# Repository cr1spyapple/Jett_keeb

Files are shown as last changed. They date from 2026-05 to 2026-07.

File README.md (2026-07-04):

# JETT
<b> A wired 56 key split keyboard powered by RP2040 microcontrollers.
</b>

3D render:
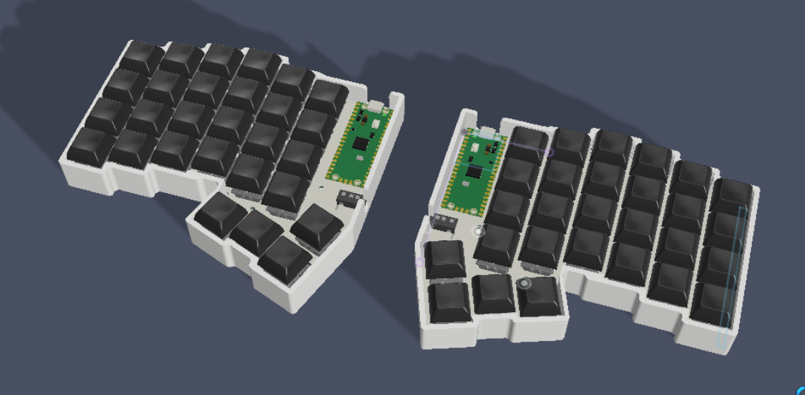
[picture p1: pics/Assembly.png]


Final build:
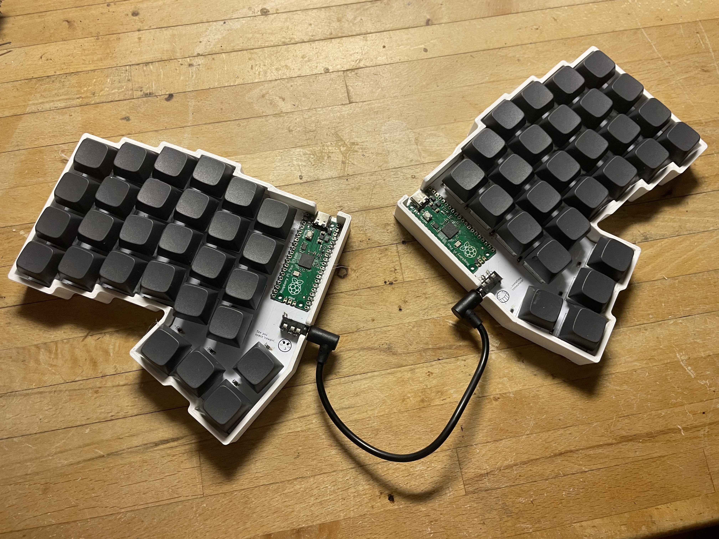
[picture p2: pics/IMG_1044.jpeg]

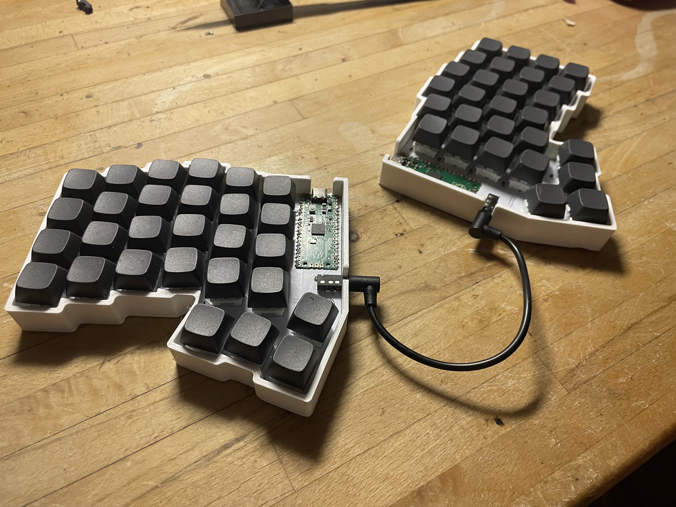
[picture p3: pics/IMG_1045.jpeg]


After creating the GOATPad i decided to take up a slightly more challenging twist to that project. This time a full split keyboard, which taught me how to panelize PCBs and make two MCU's communicate together.

  ### Specs
- Raspberry Pico microcontroller
- 56 keys
- MX Brown switches
- USB Type-C connectivity
- 3D Printed Case

## Schematic
### Left
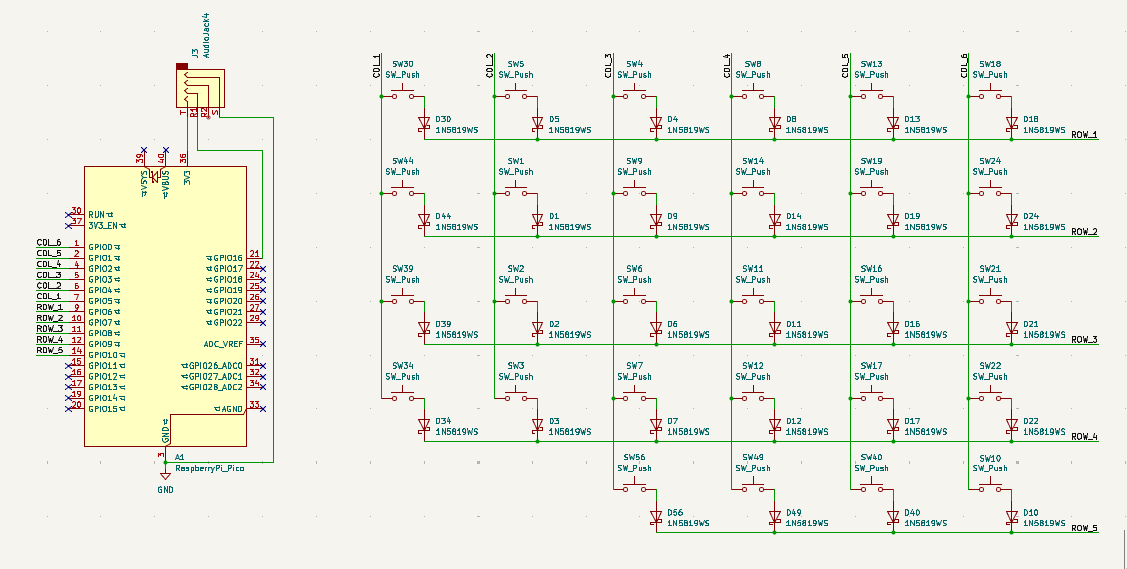
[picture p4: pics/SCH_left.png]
 

### Right
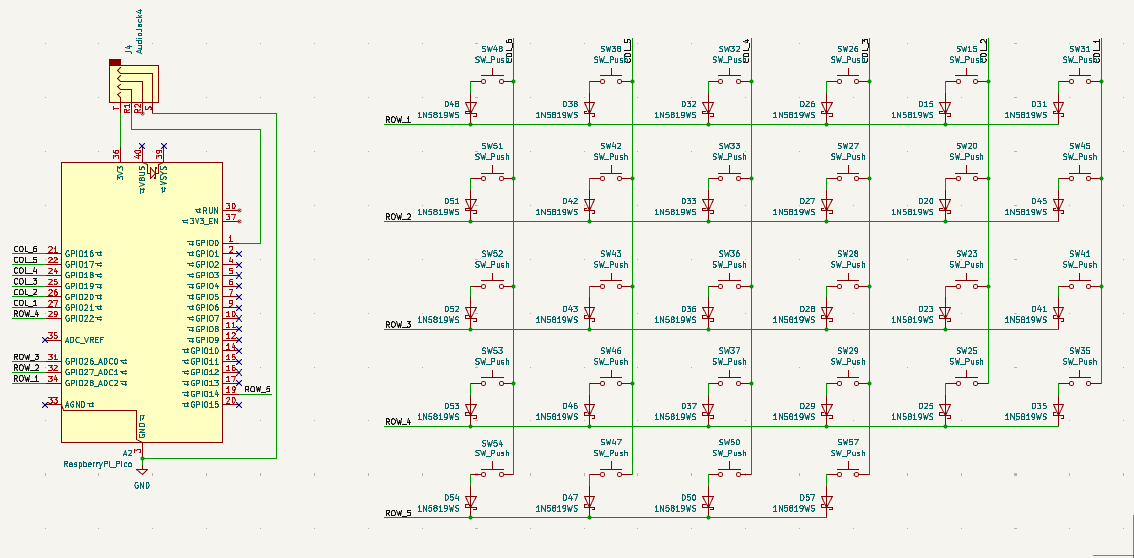
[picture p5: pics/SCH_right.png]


## PCB
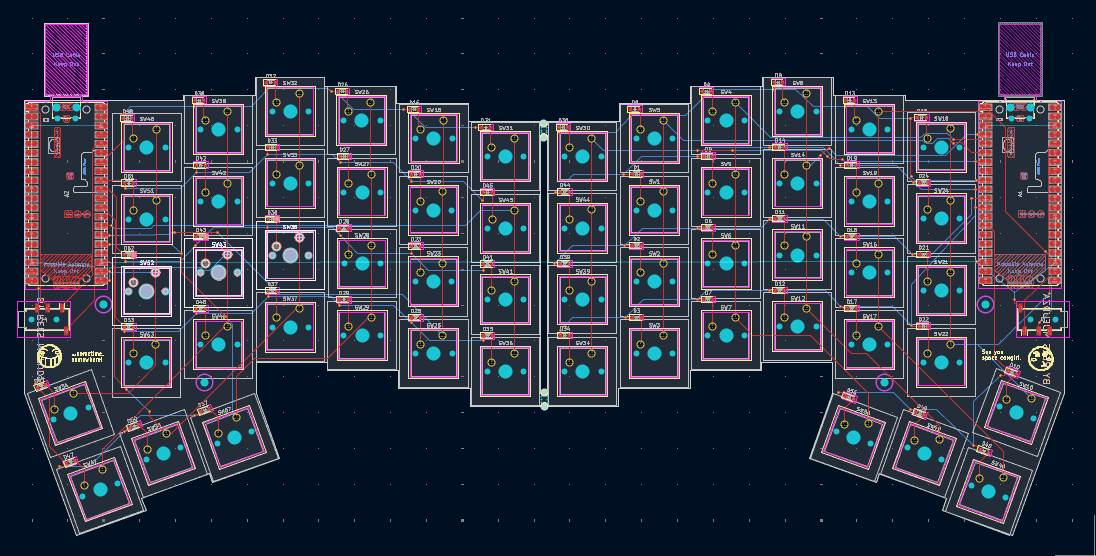
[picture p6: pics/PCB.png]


## Case
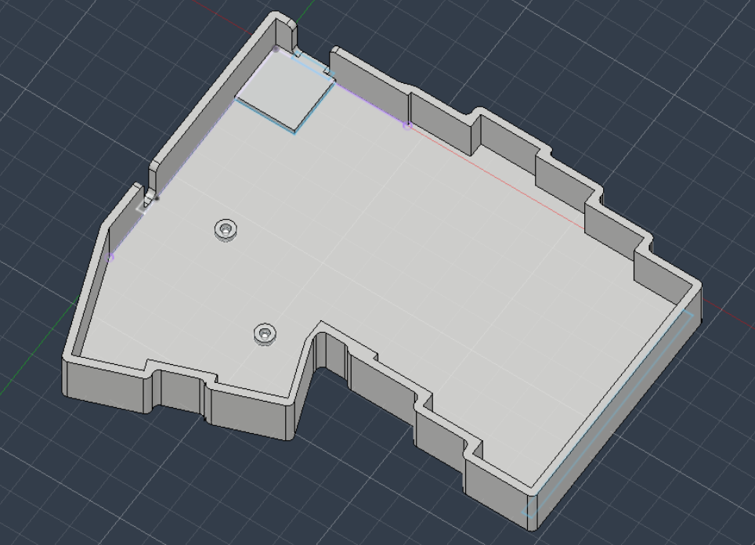
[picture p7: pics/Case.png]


## Bill of Materials

|Name |Purpose |Quantity|Total Cost (USD)|Link |Distributor|
|---|---|---|---|---|---|
|M2 Heat inserts |Screw holes in case |1 |1.95 |https://www.aliexpress.com/item/1005007640664497.html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|Aliexpress |
|M2 Screws |Mounting PCB to case |1 |1.35 |https://www.aliexpress.com/item/4000026780118.html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 |Aliexpress |
|3.5mm PJ-320D audio jack (10PCS) |Port for TRRS cable | |1.20 |https://www.aliexpress.com/item/4000661908135.html |Aliexpress |
|1N5819WS SOD-323 Diodes (100PCS) |Diodes for key matrix | |1.64 |https://www.aliexpress.com/item/1005006216984245.html |Aliexpress |
|Male-to-Male TRRS cable |For MCU's to share power and data|1 |2.50 |https://www.aliexpress.com/item/1005008288720867.html |Aliexpress |
|Black XDA Profile keycaps (64PCS)  |Key caps | |15.06 |https://www.aliexpress.com/item/1005011932744770.html?mp=1 |Aliexpress |
|MX style Brown key switches (80PCS)|Key switches | |6.91 |https://www.aliexpress.com/item/1005011838889689.html |Aliexpress |
|Raspberry Pico |Microcontroller |2 |4.55 |https://www.aliexpress.com/item/1005005617180169.html |Aliexpress |
|PCB |Keyboard PCB |5 |22.90 | |JLCPCB |
|  | TOTAL |  | 58.06 |  |  |

*Not including shipping and tax

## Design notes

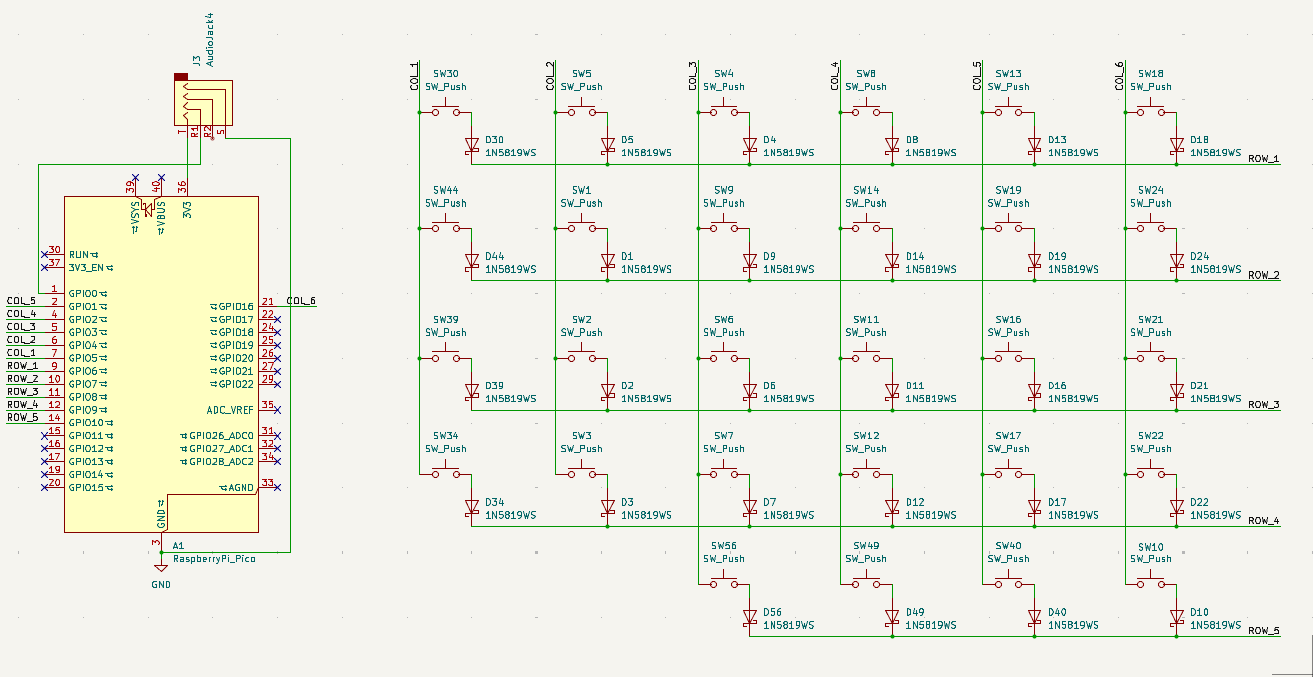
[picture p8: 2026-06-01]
pics/SCH_Left.png

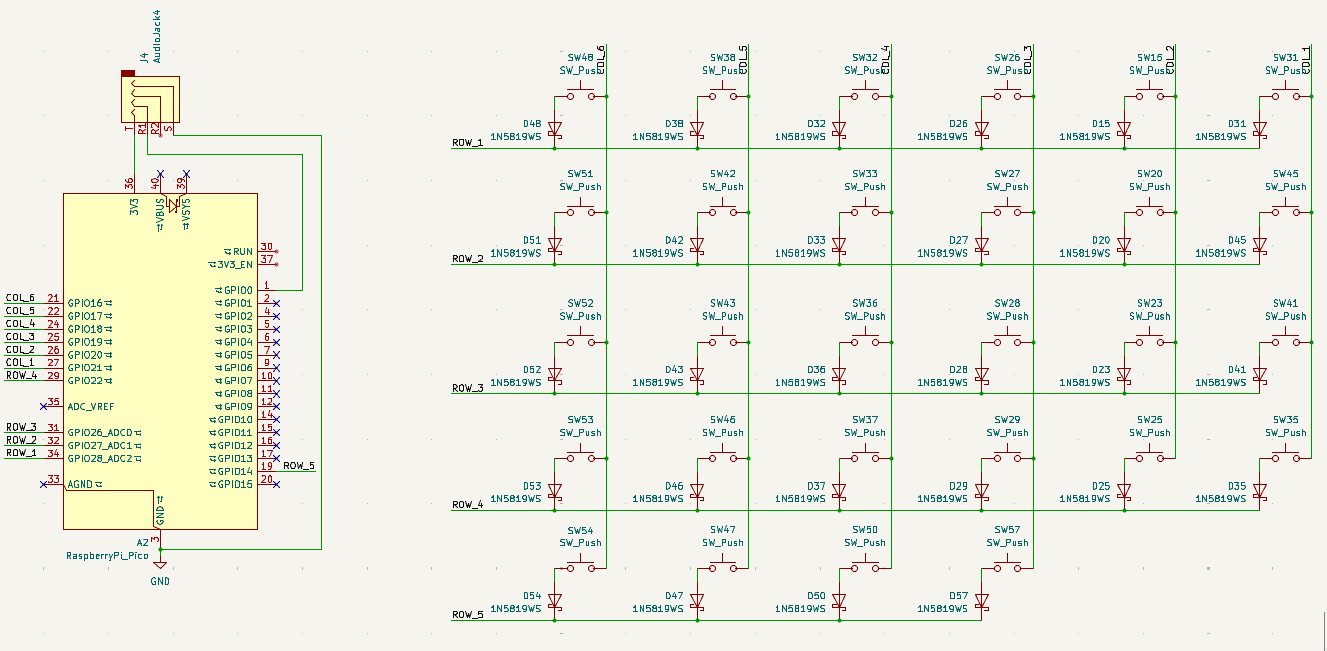
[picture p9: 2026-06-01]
pics/SCH_Right.png

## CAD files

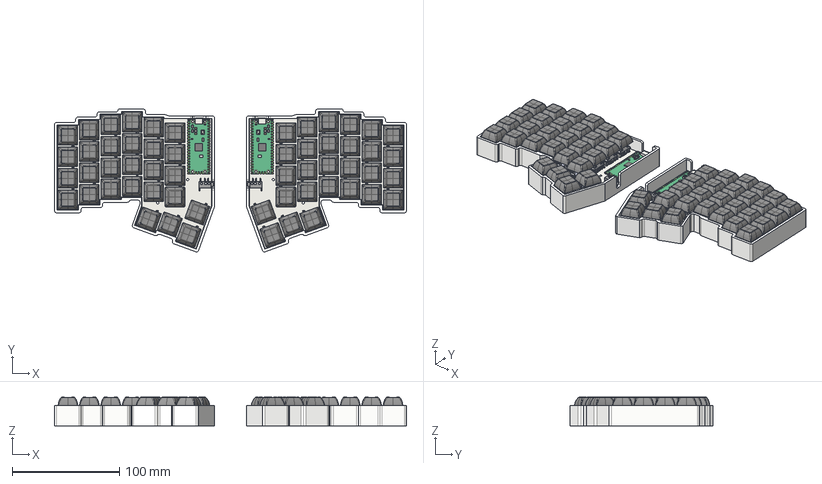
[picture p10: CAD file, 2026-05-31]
base (Assembly).step
328.7 x 133.4 x 26.7 mm
D_SOD-323 x 28
RaspberryPi_Pico_Module_KiCad
JETT_SPLIT_PCB
MX Öá °´¼ü¡ä_¨¹ ___¡§1 x 28
MX Öá ÖáÌå¨¢¨¬ _¡§¡é¡§__ x 28
MXÖá ÎÞÃ±LEDLEDLED x 28
MXÖá ÖáÌå µ×²¿ ¦Ì¡ Á2__Ä¬ÈÏ_¨¢2____¨¨_ x 28
Õë½Å___Ä¬ÈÏ__¨¨ _ x 28
Keycap_adjusted x 28
Composant1.step
audio_3.5mm_trrs.step
audio_3.5mm_trrs-0.step
audio_3.5mm_trrs-1.step
audio_3.5mm_trrs-2.step
audio_3.5mm_trrs-3.step
audio_3.5mm_trrs-4.step
audio_3.5mm_trrs-5.step
audio_3.5mm_trrs-6.step
audio_3.5mm_trrs-7.step
audio_3.5mm_trrs-8.step
audio_3.5mm_trrs-9.step
audio_3.5mm_trrs-10.step
audio_3.5mm_trrs-11.step
audio_3.5mm_trrs-12.step
audio_3.5mm_trrs-13.step

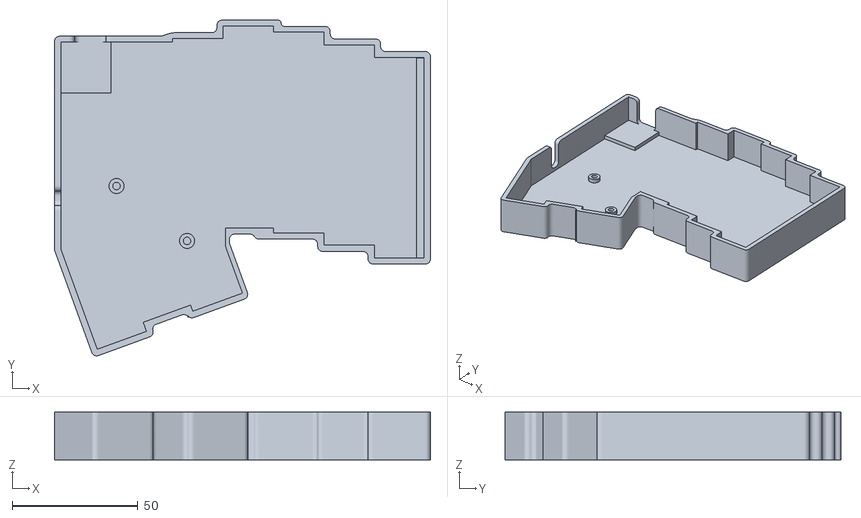
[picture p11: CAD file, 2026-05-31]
production/JETT_case.stl
149.3 x 133.4 x 19.0

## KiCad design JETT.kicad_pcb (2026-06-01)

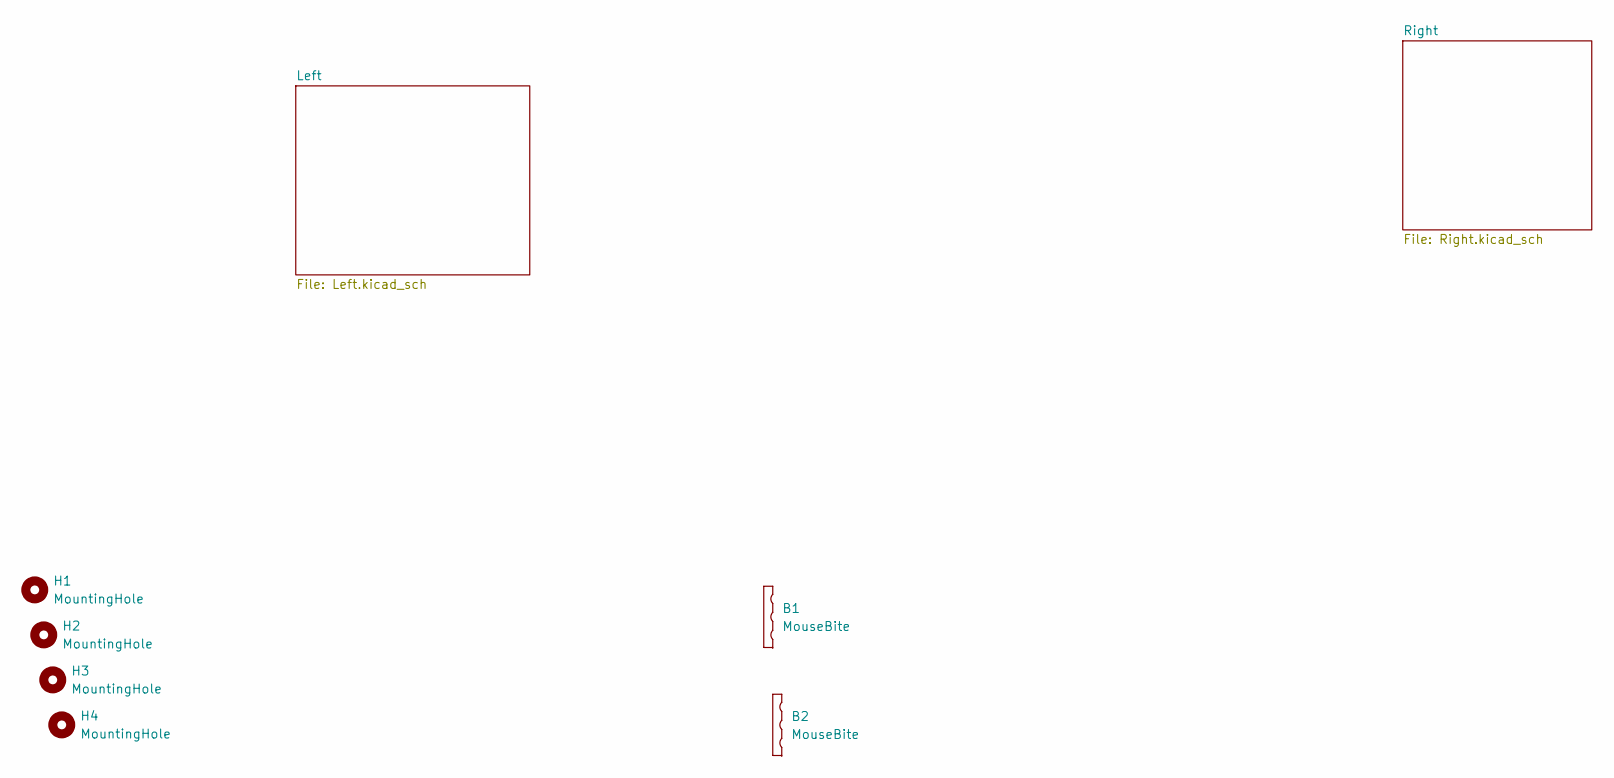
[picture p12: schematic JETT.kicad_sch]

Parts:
B1, B2: MouseBite; mouse-bite-2mm-slot
H1, H2, H3, H4: MountingHole; MountingHole_2.2mm_M2

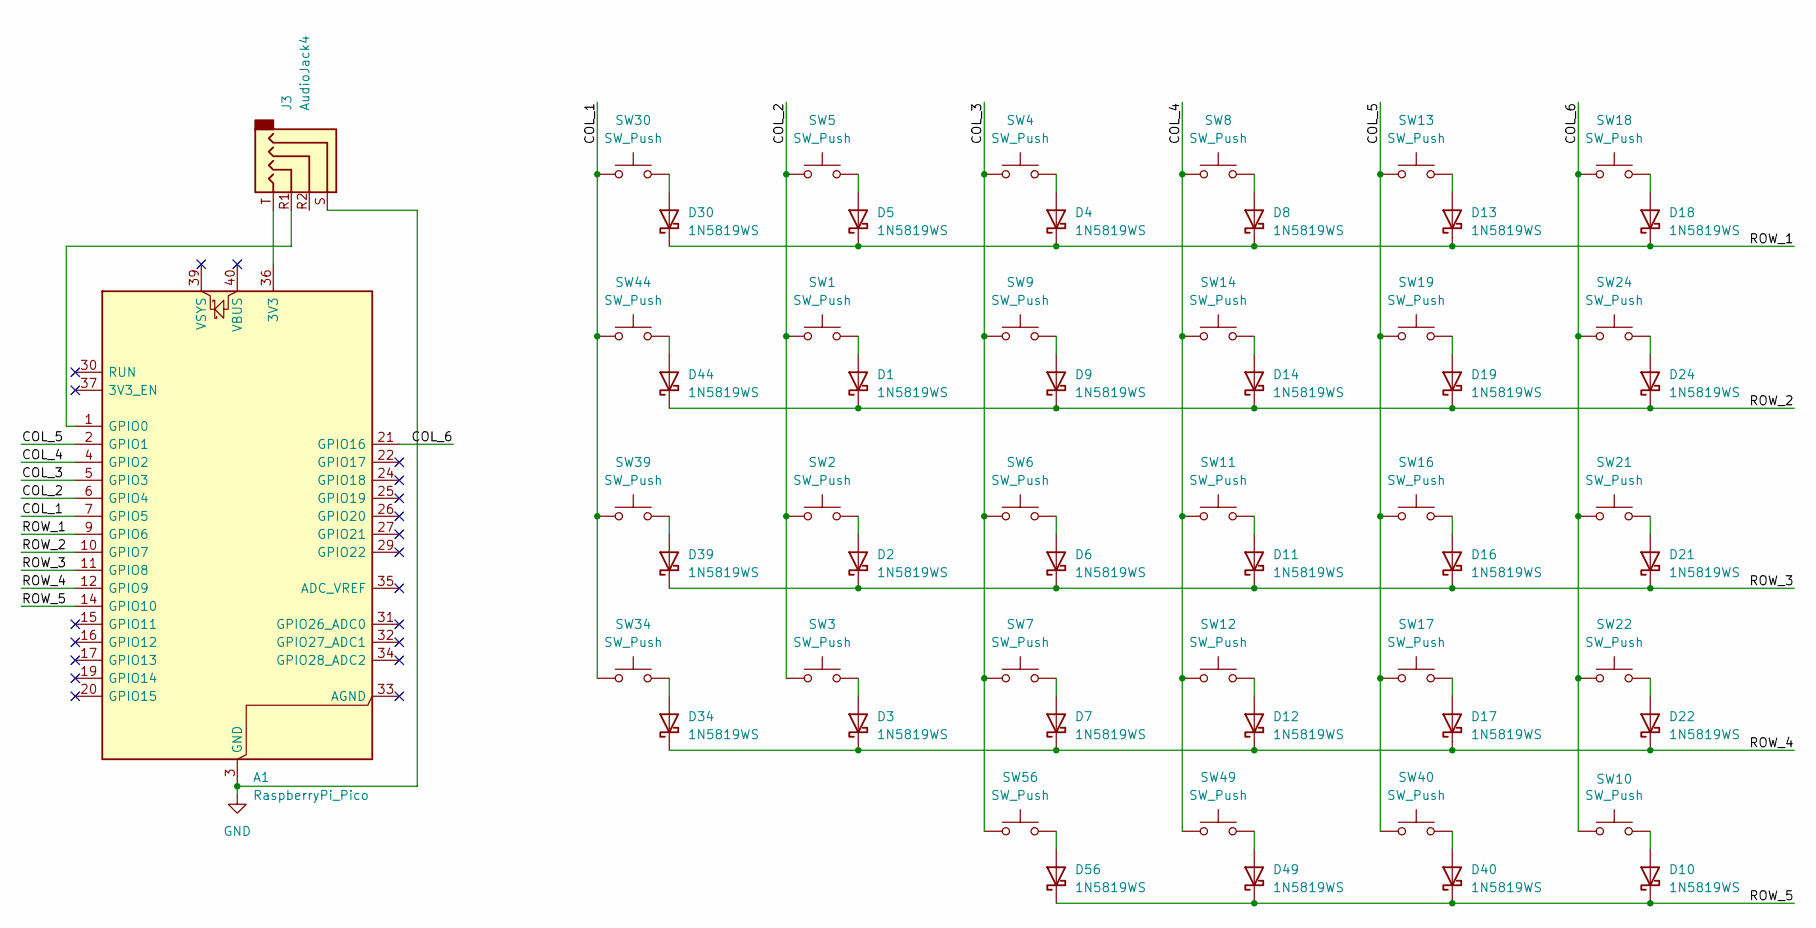
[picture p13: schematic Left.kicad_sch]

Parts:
A1: RaspberryPi_Pico; RaspberryPi_Pico_Common_SMD
D1, D2, D3, D4, D5, D6, D7, D8, D9, D10, D11, D12, D13, D14, D16, D17, D18, D19, D21, D22, D24, D30, D34, D39, D40, D44, D49, D56: 1N5819WS; D_SOD-323_HandSoldering
J3: AudioJack4; Jack_3.5mm_PJ320D_Horizontal
SW1, SW2, SW3, SW4, SW5, SW6, SW7, SW8, SW9, SW10, SW11, SW12, SW13, SW14, SW16, SW17, SW18, SW19, SW21, SW22, SW24, SW30, SW34, SW39, SW40, SW44, SW49, SW56: SW_Push; SW_Cherry_MX_1.00u_PCB

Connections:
/Left/COL_1: A1.7 (GPIO5), SW30.1, SW34.1, SW39.1, SW44.1
/Left/COL_2: A1.6 (GPIO4), SW1.1, SW2.1, SW3.1, SW5.1
/Left/COL_3: A1.5 (GPIO3), SW4.1, SW6.1, SW7.1, SW9.1, SW56.1
/Left/COL_4: A1.4 (GPIO2), SW8.1, SW11.1, SW12.1, SW14.1, SW49.1
/Left/COL_5: A1.2 (GPIO1), SW13.1, SW16.1, SW17.1, SW19.1, SW40.1
/Left/COL_6: A1.21 (GPIO16), SW10.1, SW18.1, SW21.1, SW22.1, SW24.1
/Left/ROW_1: A1.9 (GPIO6), D4.1 (K), D5.1 (K), D8.1 (K), D13.1 (K), D18.1 (K), D30.1 (K)
/Left/ROW_2: A1.10 (GPIO7), D1.1 (K), D9.1 (K), D14.1 (K), D19.1 (K), D24.1 (K), D44.1 (K)
/Left/ROW_3: A1.11 (GPIO8), D2.1 (K), D6.1 (K), D11.1 (K), D16.1 (K), D21.1 (K), D39.1 (K)
/Left/ROW_4: A1.12 (GPIO9), D3.1 (K), D7.1 (K), D12.1 (K), D17.1 (K), D22.1 (K), D34.1 (K)
/Left/ROW_5: A1.14 (GPIO10), D10.1 (K), D40.1 (K), D49.1 (K), D56.1 (K)
GND: A1.3 (GND), A1.8 (GND), A1.13 (GND), A1.18 (GND), A1.23 (GND), A1.28 (GND), A1.38 (GND), J3.S; also elsewhere on the board
unnamed: A1.36 (3V3), J3.T
unnamed: A1.1 (GPIO0), J3.R1
unnamed: D1.2 (A), SW1.2
unnamed: D2.2 (A), SW2.2
unnamed: D3.2 (A), SW3.2
unnamed: D4.2 (A), SW4.2
unnamed: D5.2 (A), SW5.2
unnamed: D6.2 (A), SW6.2
unnamed: D7.2 (A), SW7.2
unnamed: D8.2 (A), SW8.2
unnamed: D9.2 (A), SW9.2
unnamed: D10.2 (A), SW10.2
unnamed: D11.2 (A), SW11.2
unnamed: D12.2 (A), SW12.2
unnamed: D13.2 (A), SW13.2
unnamed: D14.2 (A), SW14.2
unnamed: D16.2 (A), SW16.2
unnamed: D17.2 (A), SW17.2
unnamed: D18.2 (A), SW18.2
unnamed: D19.2 (A), SW19.2
unnamed: D21.2 (A), SW21.2
unnamed: D22.2 (A), SW22.2
unnamed: D24.2 (A), SW24.2
unnamed: D30.2 (A), SW30.2
unnamed: D34.2 (A), SW34.2
unnamed: D39.2 (A), SW39.2
unnamed: D40.2 (A), SW40.2
unnamed: D44.2 (A), SW44.2
unnamed: D49.2 (A), SW49.2
unnamed: D56.2 (A), SW56.2

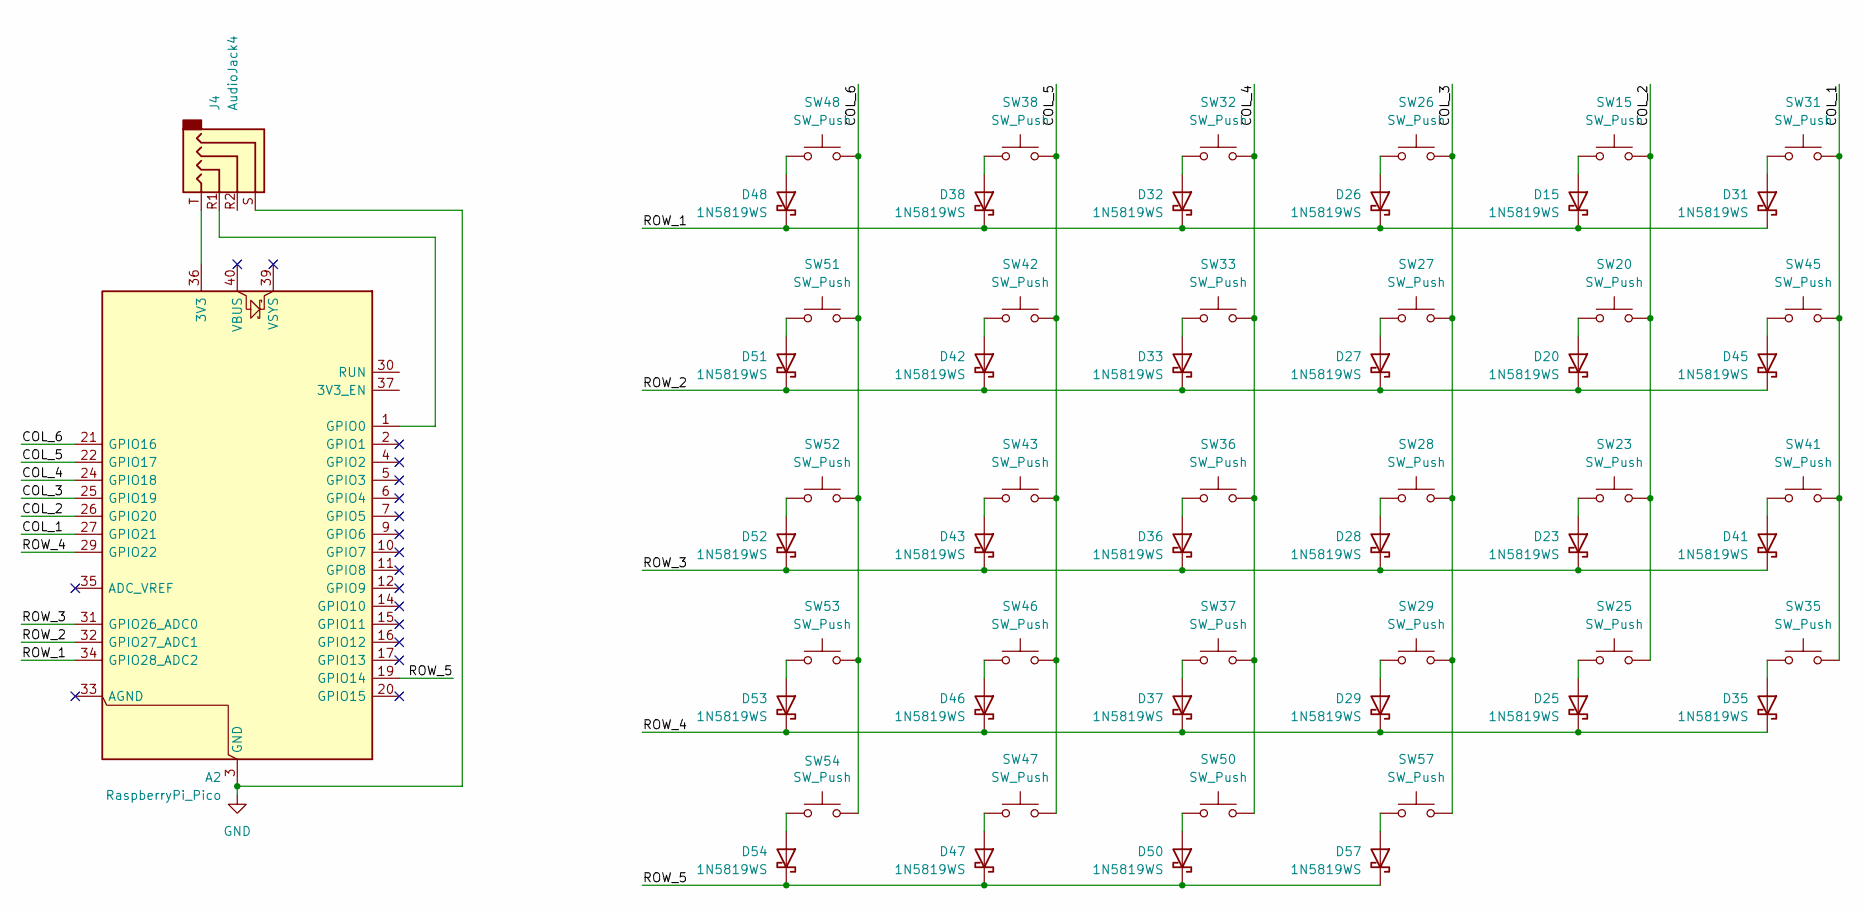
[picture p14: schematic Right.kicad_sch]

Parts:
A2: RaspberryPi_Pico; RaspberryPi_Pico_Common_SMD
D15, D20, D23, D25, D26, D27, D28, D29, D31, D32, D33, D35, D36, D37, D38, D41, D42, D43, D45, D46, D47, D48, D50, D51, D52, D53, D54, D57: 1N5819WS; D_SOD-323_HandSoldering
J4: AudioJack4; Jack_3.5mm_PJ320D_Horizontal
SW15, SW20, SW23, SW25, SW26, SW27, SW28, SW29, SW31, SW32, SW33, SW35, SW36, SW37, SW38, SW41, SW42, SW43, SW45, SW46, SW47, SW48, SW50, SW51, SW52, SW53, SW54, SW57: SW_Push; SW_Cherry_MX_1.00u_PCB

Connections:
/Right/COL_1: A2.27 (GPIO21), SW31.1, SW35.1, SW41.1, SW45.1
/Right/COL_2: A2.26 (GPIO20), SW15.1, SW20.1, SW23.1, SW25.1
/Right/COL_3: A2.25 (GPIO19), SW26.1, SW27.1, SW28.1, SW29.1, SW57.1
/Right/COL_4: A2.24 (GPIO18), SW32.1, SW33.1, SW36.1, SW37.1, SW50.1
/Right/COL_5: A2.22 (GPIO17), SW38.1, SW42.1, SW43.1, SW46.1, SW47.1
/Right/COL_6: A2.21 (GPIO16), SW48.1, SW51.1, SW52.1, SW53.1, SW54.1
/Right/ROW_1: A2.34 (GPIO28_ADC2), D15.1 (K), D26.1 (K), D31.1 (K), D32.1 (K), D38.1 (K), D48.1 (K)
/Right/ROW_2: A2.32 (GPIO27_ADC1), D20.1 (K), D27.1 (K), D33.1 (K), D42.1 (K), D45.1 (K), D51.1 (K)
/Right/ROW_3: A2.31 (GPIO26_ADC0), D23.1 (K), D28.1 (K), D36.1 (K), D41.1 (K), D43.1 (K), D52.1 (K)
/Right/ROW_4: A2.29 (GPIO22), D25.1 (K), D29.1 (K), D35.1 (K), D37.1 (K), D46.1 (K), D53.1 (K)
/Right/ROW_5: A2.19 (GPIO14), D47.1 (K), D50.1 (K), D54.1 (K), D57.1 (K)
GND: A2.3 (GND), A2.8 (GND), A2.13 (GND), A2.18 (GND), A2.23 (GND), A2.28 (GND), A2.38 (GND), J4.S; also elsewhere on the board
unnamed: A2.36 (3V3), J4.T
unnamed: A2.1 (GPIO0), J4.R1
unnamed: D15.2 (A), SW15.2
unnamed: D20.2 (A), SW20.2
unnamed: D23.2 (A), SW23.2
unnamed: D25.2 (A), SW25.2
unnamed: D26.2 (A), SW26.2
unnamed: D27.2 (A), SW27.2
unnamed: D28.2 (A), SW28.2
unnamed: D29.2 (A), SW29.2
unnamed: D31.2 (A), SW31.2
unnamed: D32.2 (A), SW32.2
unnamed: D33.2 (A), SW33.2
unnamed: D35.2 (A), SW35.2
unnamed: D36.2 (A), SW36.2
unnamed: D37.2 (A), SW37.2
unnamed: D38.2 (A), SW38.2
unnamed: D41.2 (A), SW41.2
unnamed: D42.2 (A), SW42.2
unnamed: D43.2 (A), SW43.2
unnamed: D45.2 (A), SW45.2
unnamed: D46.2 (A), SW46.2
unnamed: D47.2 (A), SW47.2
unnamed: D48.2 (A), SW48.2
unnamed: D50.2 (A), SW50.2
unnamed: D51.2 (A), SW51.2
unnamed: D52.2 (A), SW52.2
unnamed: D53.2 (A), SW53.2
unnamed: D54.2 (A), SW54.2
unnamed: D57.2 (A), SW57.2

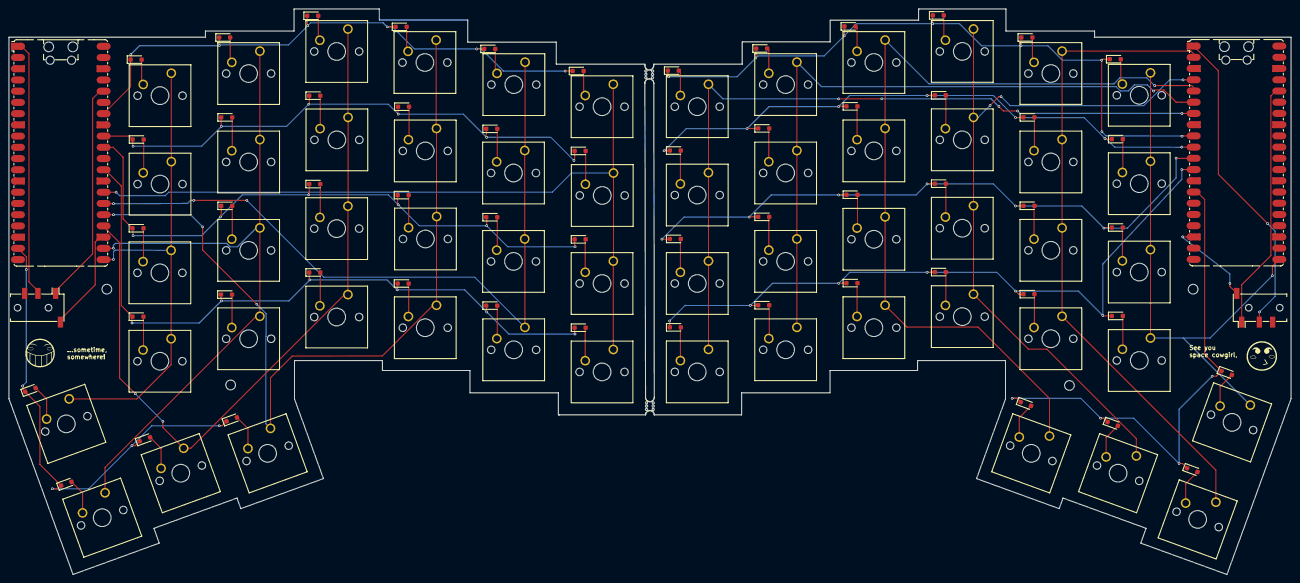
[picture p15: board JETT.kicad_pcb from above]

Board: 2 copper layers, 290.1 x 128.0 mm, 122 parts (0 on the bottom side), 83 nets.

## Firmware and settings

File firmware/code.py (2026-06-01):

print("Starting")
import board
from kmk.kmk_keyboard import KMKKeyboard
from kmk.keys import KC
from kmk.scanners import DiodeOrientation
from kb import data_pin
from kmk.modules.split import Split, SplitSide
from storage import getmount

keyboard = KMKKeyboard()

side = SplitSide.RIGHT if str(getmount('/').label)[-1] == 'R' else SplitSide.LEFT

if side == SplitSide.RIGHT:
    keyboard.col_pins = (board.GP21, board.GP20, board.GP19, board.GP18, board.GP17, board.GP16) 
    keyboard.row_pins = (board.GP28, board.GP27, board.GP26, board.GP22, board.GP14)
    keyboard.diode_orientation = DiodeOrientation.COL2ROW 
    keyboard.keymap = [
    [
        KC.N7, KC.N8, KC.N9, KC.N0, KC.MINS, KC.EQL,
        KC.Y, KC.U, KC.I, KC.O, KC.P, KC.BSPC,
        KC.H, KC.J, KC.K, KC.L, KC.SCLN, KC.QUOT,
        KC.N, KC.M, KC.COMM, KC.DOT, KC.SLSH, KC.NO,
        KC.SPC, KC.RSFT, KC.RCTL, KC.NO, KC.NO, KC.NO
    ]
]
else:
    keyboard.col_pins = (board.GP5, board.GP4, board.GP3, board.GP2, board.GP1, board.GP16) 
    keyboard.row_pins = (board.GP6, board.GP7, board.GP8, board.GP9, board.GP10)
    keyboard.diode_orientation = DiodeOrientation.COL2ROW
    keyboard.keymap = [
    [
        KC.N1, KC.N2, KC.N3, KC.N4, KC.N5, KC.N6,
        KC.Q, KC.W, KC.E, KC.R, KC.T, KC.Y,
        KC.A, KC.S, KC.D, KC.F, KC.G, KC.H,
        KC.Z, KC.X, KC.C, KC.V, KC.B, KC.NO,
        KC.NO, KC.NO, KC.MO(1), KC.SPC, KC.LSFT, KC.LCTL
    ]
]

split = Split(split_side=none,  data_pin=GP0)
keyboard.modules.append(split)

if __name__ == '__main__':
    keyboard.go()
